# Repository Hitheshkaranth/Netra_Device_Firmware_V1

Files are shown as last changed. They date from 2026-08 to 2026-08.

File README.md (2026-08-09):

<p align="center">
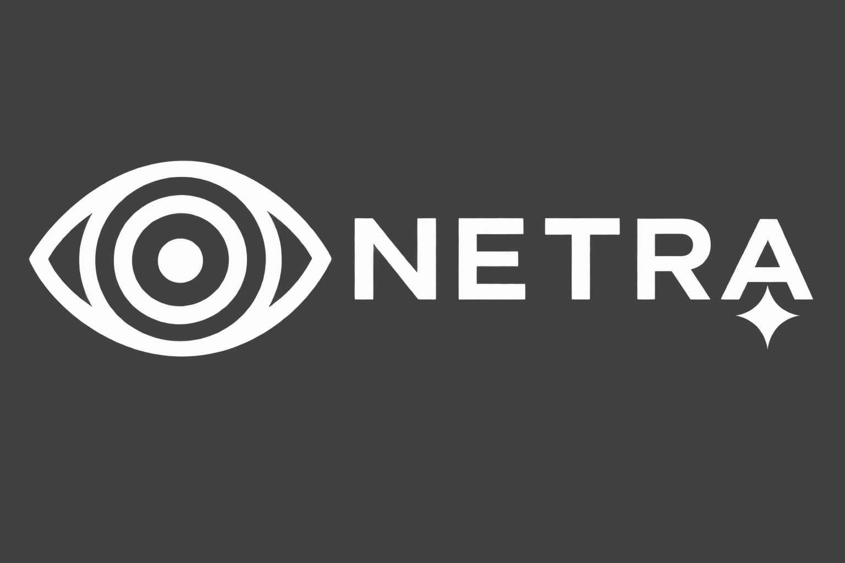
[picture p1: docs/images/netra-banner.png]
NETRA
  
</p>

<div align="center">

# NETRA Device Firmware V1

### ESP32-C6 spatial-sensing firmware for the NETRA wearable safety system








Ultrasonic ranging and six-axis motion telemetry, streamed as clean CSV over USB serial.

**Built for Claude Community Events @ Impact Lab.**

</div>

## Hardware

<p align="center">
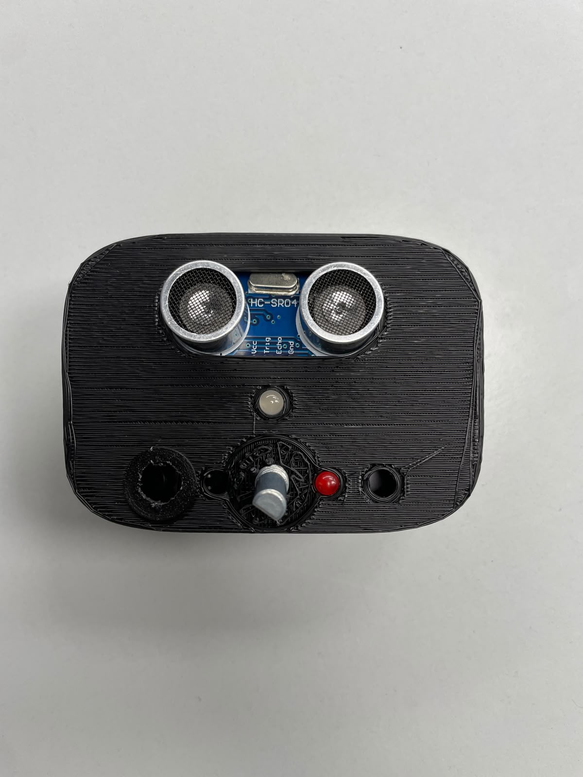
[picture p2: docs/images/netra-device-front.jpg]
NETRA device front view
  
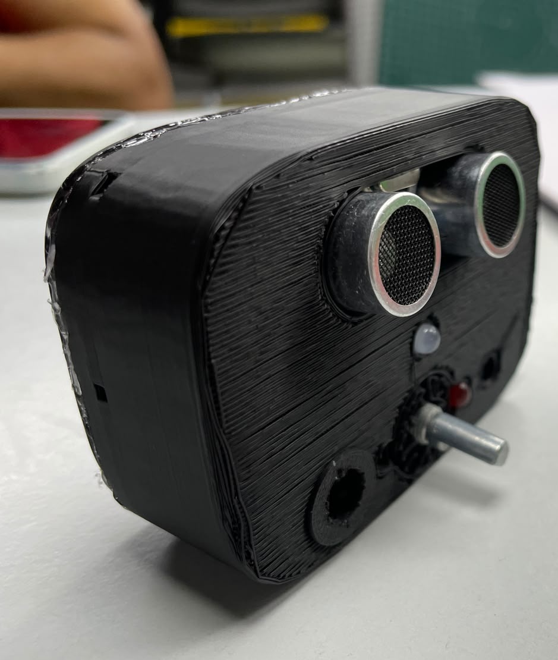
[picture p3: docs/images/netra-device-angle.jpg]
NETRA device angled view
  
</p>

The V1 sensor node combines:

| Component | Purpose | Interface |
|---|---|---|
| PCBCupid Glyph C6 / ESP32-C6 | Main controller and USB serial link | USB CDC |
| HC-SR04 | Obstacle distance measurement, nominally 2–400 cm | Trigger/echo pulse |
| MPU6050 | 3-axis acceleration, 3-axis angular velocity, temperature | I²C at `0x68` or `0x69` |

The MPU6050 is read directly through `Wire`; no third-party sensor library is required.

## Wearer movement tracking

NETRA does more than measure nearby obstacles. The device is worn by the user, so its MPU6050 continuously captures the wearer's three-axis acceleration and three-axis rotation. The firmware streams this motion telemetry to the companion debugger, where it can be used to detect movement, estimate gait intensity, follow orientation changes, and animate the user's motion inside a closed or indoor tracking environment.

This is relative inertial movement tracking rather than GPS-style absolute positioning. Long-term position estimation from an IMU alone will accumulate drift; the current system is designed for live movement state, posture/orientation response, and closed-environment visualization.

## Pin map

| Sensor pin | Board pin | GPIO | Direction | Notes |
|---|---|---:|---|---|
| HC-SR04 `VCC` | `5V` | — | Power | Use the board's 5 V rail |
| HC-SR04 `GND` | `GND` | — | Power | All grounds must be common |
| HC-SR04 `TRIG` | `D20` | 20 | Output | 10 µs trigger pulse |
| HC-SR04 `ECHO` | `D15` | 15 | Input | **Must pass through a voltage divider** |
| MPU6050 `VCC` | `3V3` | — | Power | Safe default for common breakout boards |
| MPU6050 `GND` | `GND` | — | Power | Common ground |
| MPU6050 `SDA` | `SDA` | 4 | I²C data | Internal address auto-detected |
| MPU6050 `SCL` | `SCL` | 5 | I²C clock | Bus runs at 100 kHz |

### Prototype connection

The breadboard prototype below shows the Glyph controller connected to the HC-SR04 ultrasonic sensor and MPU6050 IMU. Use the pin table above as the source of truth; jumper-wire colors may differ between builds.

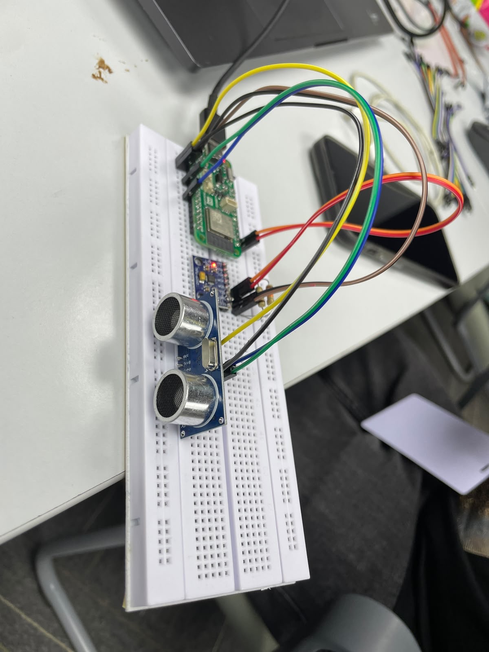
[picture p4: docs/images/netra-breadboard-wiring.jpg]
NETRA Glyph, HC-SR04, and MPU6050 breadboard connection


> [!CAUTION]
> The HC-SR04 echo output is approximately 5 V. Never connect it directly to an ESP32-C6 input. Use, for example, 1 kΩ from `ECHO` to GPIO 15 and 2 kΩ from GPIO 15 to GND to reduce the signal to approximately 3.3 V.

```text
HC-SR04 ECHO ── 1 kΩ ──┬── GPIO 15
                       │
                      2 kΩ
                       │
                      GND
```

## Build and upload

### Arduino IDE

Follow the official **[PCBCupid Arduino IDE setup guide](https://learn.pcbcupid.com/documentation/welcome/prerequisites/arduino-ide-setup)** when preparing a Glyph board. The required setup is summarized here:

1. Install the latest [Arduino IDE](https://www.arduino.cc/en/software), preferably version **2.3 or newer**.
2. Open **File → Preferences** and add this URL under **Additional Boards Manager URLs**:

   ```text
   https://raw.githubusercontent.com/espressif/arduino-esp32/gh-pages/package_esp32_index.json
   ```

3. Open **Boards Manager**, search for `ESP32`, and install **esp32 by Espressif Systems**. Use the newest available release or at least version **3.1.0**.
4. Connect the Glyph C6 with a data/sync-capable USB cable.
5. Select **Tools → Board → ESP32 Arduino → GLYPHC6**. If that entry is unavailable, select **ESP32C6 Dev Module**.
6. Open `Netra_Device_Firmware_V1.ino`, enable **Tools → USB CDC On Boot**, and select the board's COM port under **Tools → Port**.
7. Click **Verify** and confirm compilation finishes successfully, then click **Upload**.
8. After upload, open Serial Monitor at **115200 baud**.

If the COM port is missing, hold **BOOT**, press and release **RESET** while continuing to hold BOOT, then release BOOT after the board enters bootloader mode. Re-select the COM port and upload again.

### Arduino CLI

Replace `COM6` and the FQBN when using another board definition:

```powershell
arduino-cli core update-index
arduino-cli core install esp32:esp32
arduino-cli compile --fqbn esp32:esp32:esp32c6 .
arduino-cli upload -p COM6 --fqbn esp32:esp32:esp32c6 .
```

## Mechanical enclosure and 3D printing

Printable NETRA V1 enclosure and wearable-pod models are maintained separately from the firmware source under [`mechanical/`](mechanical/). The directory contains six STL parts plus slicing, printing, dry-fit, and assembly instructions.

The [interactive assembled-system viewer](mechanical/belt_system_viewer.html) renders the printable enclosure together with the belt, controller, sensors, controls, battery, and pod components. It includes ghost-shell, part-visibility, rotate, fit, and exploded-view controls.

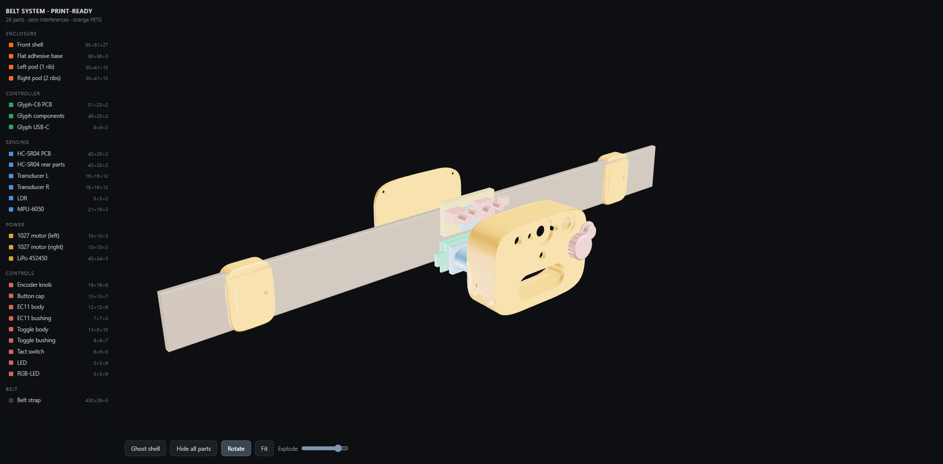
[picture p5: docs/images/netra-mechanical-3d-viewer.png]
NETRA belt system and 3D-printing assembly viewer


```text
mechanical/stl/
├── pod_1027_left.stl
├── pod_1027_right.stl
├── v2_button_cap.stl
├── v3_knob.stl
├── v7_base.stl
└── v7_shell.stl
```

See the [mechanical and 3D-printing guide](mechanical/README.md) before printing or installing electronics.

## Serial protocol

The device publishes one row every 250 ms:

```text
distance_cm,echo_us,ax_g,ay_g,az_g,gx_dps,gy_dps,gz_dps,temp_c,status
24.63,1436,0.012,-0.021,0.998,0.31,-0.18,0.07,28.41,RANGE_OK|IMU_OK
```

| Field | Unit | Meaning |
|---|---|---|
| `distance_cm` | cm | Distance calculated from the HC-SR04 echo pulse |
| `echo_us` | µs | Raw ultrasonic round-trip pulse width |
| `ax_g`…`az_g` | g | Accelerometer axes |
| `gx_dps`…`gz_dps` | °/s | Gyroscope axes |
| `temp_c` | °C | IMU die temperature |
| `status` | — | Combined range and IMU health flags |

`RANGE_TIMEOUT` indicates that no echo arrived within 30 ms. `IMU_ERROR` usually points to I²C wiring, power, or address trouble.

## Use with the NETRA debugger

Install and run the companion [Netra System Debugger V1](../Netra_System_Debugger_V1) to visualize motion, sensor health, proximity, and the live 3D digital twin.

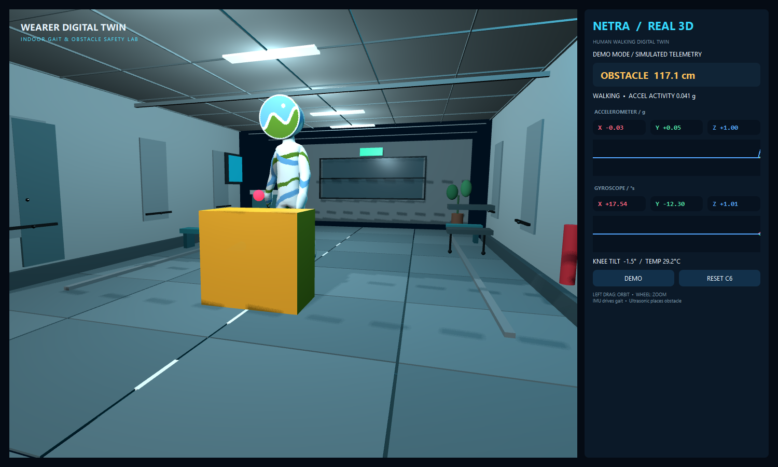
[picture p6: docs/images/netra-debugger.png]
NETRA PySide6 3D debugger


Only one application can own the serial port at a time. Close Arduino Serial Monitor before starting the debugger.

## Quick checks

- At rest, the magnitude of `(ax, ay, az)` should be close to `1 g`.
- Rotating the enclosure should change the gyroscope values.
- A flat target between 10 and 100 cm should produce a stable distance.
- If the board prints ROM download messages, tap reset and confirm **USB CDC On Boot** is enabled.

## Repository layout

```text
Netra_Device_Firmware_V1/
├── Netra_Device_Firmware_V1.ino
├── docs/images/
├── mechanical/
│   ├── README.md
│   ├── belt_system_viewer.html
│   └── stl/*.stl
├── .gitignore
└── README.md
```

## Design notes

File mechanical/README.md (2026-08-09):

# NETRA mechanical and 3D-printing files

This directory contains the printable enclosure parts for the NETRA V1 wearable sensor device. The source STL filenames are preserved so they can be traced back to the original mechanical export.

## Interactive assembled-system viewer

Open [`belt_system_viewer.html`](belt_system_viewer.html) in a modern browser to inspect the complete belt system, enclosure, controller, sensors, controls, power components, and wearable pods in an interactive 3D scene.

The viewer provides:

- orbit, pan, zoom, automatic rotation, and fit-to-view controls;
- a ghosted enclosure mode for inspecting internal placement;
- per-part visibility controls and component dimensions;
- an explode slider for separating the assembly;
- embedded model geometry, with only the Three.js runtime loaded externally.

An internet connection is required when opening the viewer because it loads Three.js from cdnjs.

NETRA belt system and printable enclosure assembly

## Printer and slicer used

The photographed NETRA enclosure print job was prepared in **Bambu Studio** for a **Bambu Lab P2S 3D printer**. The slicer preview used a 0.20 mm layer profile with automatic tree supports; the pictured plate estimated approximately 55.7 g of filament and 2 hours 10 minutes total print time. Treat these values as a record of this prototype build—re-slice the STL files for your own printer, nozzle, filament, and calibration.

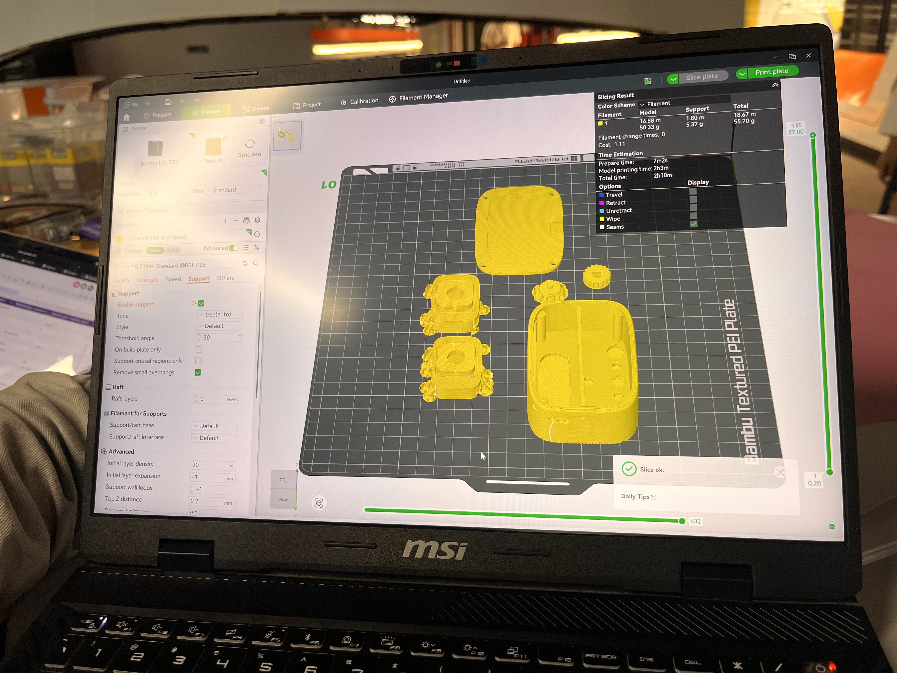
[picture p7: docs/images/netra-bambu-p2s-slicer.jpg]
NETRA enclosure parts sliced for the Bambu Lab P2S


## Included parts

| File | Intended part |
|---|---|
| [`pod_1027_left.stl`](stl/pod_1027_left.stl) | Left wearable pod component |
| [`pod_1027_right.stl`](stl/pod_1027_right.stl) | Right wearable pod component |
| [`v2_button_cap.stl`](stl/v2_button_cap.stl) | External button cap |
| [`v3_knob.stl`](stl/v3_knob.stl) | User-control knob |
| [`v7_base.stl`](stl/v7_base.stl) | Main enclosure base |
| [`v7_shell.stl`](stl/v7_shell.stl) | Main enclosure shell/top cover |

## Prepare the files

1. Download this repository or the individual STL files.
2. Import the required models from `mechanical/stl/` into Cura, PrusaSlicer, OrcaSlicer, Bambu Studio, or another STL-compatible slicer.
3. Treat the models as millimetres. Confirm the displayed dimensions before slicing; do not rescale unless your slicer imported them in another unit.
4. Place the largest flat surface on the build plate where practical.
5. Inspect the HC-SR04 openings, button/knob features, overhangs, and internal mounting points in the layer preview. Enable supports only where the selected orientation needs them.

## Suggested starting profile

These values are a safe prototype starting point, not a substitute for tuning your printer and material:

| Setting | Starting value |
|---|---|
| Material | PLA for prototypes; PETG for improved impact/heat resistance |
| Layer height | 0.20 mm |
| Walls/perimeters | 3 |
| Top and bottom layers | 4–5 |
| Infill | 20–30% |
| Supports | Build plate only, where required by preview |
| Brim | Optional for pod parts or a small bed-contact area |

## Assembly workflow

1. Print one `v7_base`, one `v7_shell`, the button cap, the knob, and the pod parts needed by your wearable configuration.
2. Remove supports and carefully deburr sensor, control, cable, and fastener openings.
3. Dry-fit the HC-SR04, controller, controls, and enclosure halves before installing fasteners or adhesive.
4. Check that the button cap and knob move freely without holding the internal switches permanently active.
5. Route wiring away from enclosure edges and moving controls. Keep the HC-SR04 transducers unobstructed.
6. Confirm the HC-SR04 echo voltage divider and common grounds before powering the assembled device.

> [!CAUTION]
> Printer tolerances and component dimensions vary. Do not force electronics into a tight print. Adjust slicer compensation or lightly finish the relevant opening, then dry-fit again.

## Directory layout

```text
mechanical/
├── README.md
├── belt_system_viewer.html
└── stl/
    ├── pod_1027_left.stl
    ├── pod_1027_right.stl
    ├── v2_button_cap.stl
    ├── v3_knob.stl
    ├── v7_base.stl
    └── v7_shell.stl
```

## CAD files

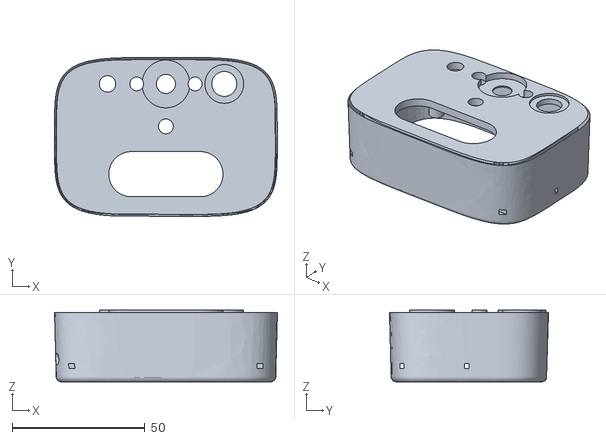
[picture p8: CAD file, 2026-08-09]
mechanical/stl/v7_shell.stl
84.0 x 59.9 x 27.0

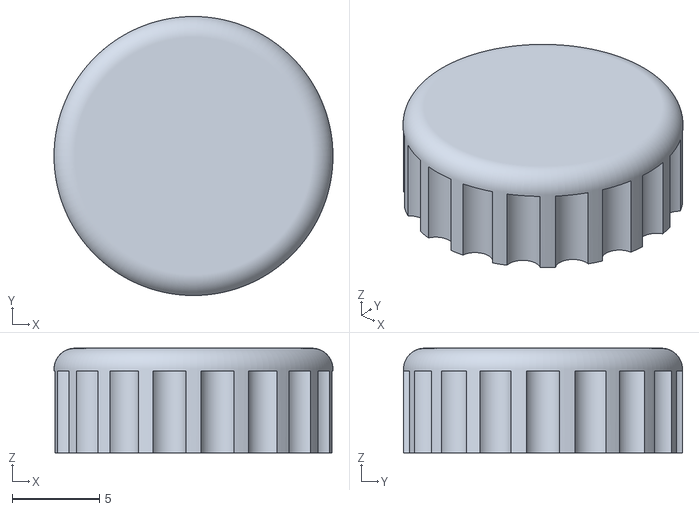
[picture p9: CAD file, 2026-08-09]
mechanical/stl/v3_knob.stl
16.0 x 16.0 x 6.00

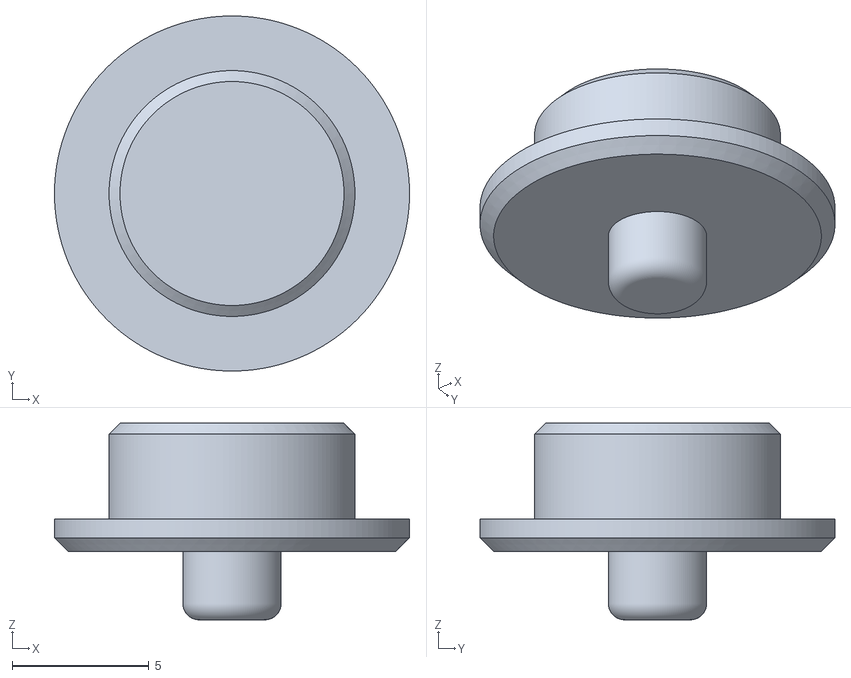
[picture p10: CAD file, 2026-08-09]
mechanical/stl/v2_button_cap.stl
13.0 x 13.0 x 7.20

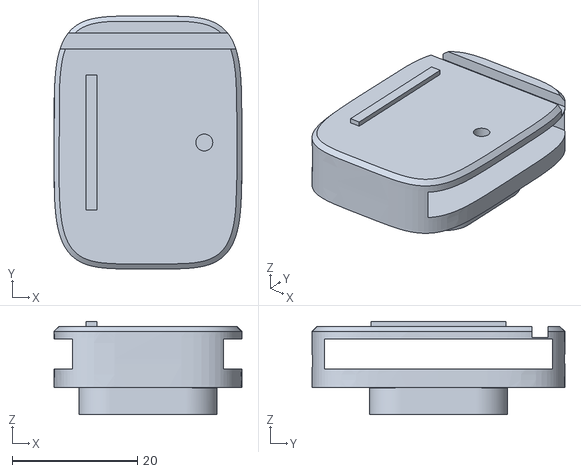
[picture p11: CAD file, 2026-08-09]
mechanical/stl/pod_1027_right.stl
30.0 x 40.4 x 14.9

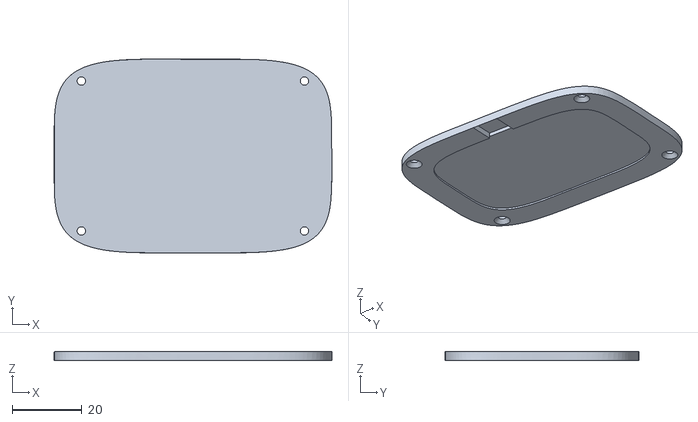
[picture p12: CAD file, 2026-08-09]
mechanical/stl/v7_base.stl
79.7 x 55.7 x 2.50

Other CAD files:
mechanical/stl/pod_1027_left.stl

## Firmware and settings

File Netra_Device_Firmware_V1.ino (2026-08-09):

#include <Arduino.h>
#include <Wire.h>

// PCBCupid Glyph C6 wiring.
constexpr uint8_t ECHO_PIN = 15;  // Board pin D15, through divider.
constexpr uint8_t TRIG_PIN = 20;  // Board pin D20.
constexpr uint8_t SDA_PIN = 4;    // Board pin SDA.
constexpr uint8_t SCL_PIN = 5;    // Board pin SCL.

constexpr uint32_t SERIAL_BAUD = 115200;
constexpr uint32_t ECHO_TIMEOUT_US = 30000;  // About 5 m maximum round trip.
constexpr uint32_t SAMPLE_PERIOD_MS = 250;

// The HC-SR04 is only specified from 2 cm to 400 cm. The echo timeout allows
// more than that, so readings beyond these bounds are reported as out of spec
// rather than passed off as measurements.
constexpr float RANGE_MIN_CM = 2.0f;
constexpr float RANGE_MAX_CM = 400.0f;

// Approximated range: the median of the last few valid readings. A median
// rejects the isolated wild values this sensor produces on a glancing or soft
// target, which a mean would instead smear across several samples.
constexpr uint8_t RANGE_WINDOW = 5;

// Proximity bands for the approximated range, nearest first.
constexpr float ZONE_IMMEDIATE_CM = 25.0f;
constexpr float ZONE_NEAR_CM = 60.0f;
constexpr float ZONE_MID_CM = 120.0f;
constexpr float ZONE_FAR_CM = 250.0f;

enum RangeStatus : uint8_t {
  RANGE_STATUS_OK,
  RANGE_STATUS_TIMEOUT,
  RANGE_STATUS_OUT_OF_SPEC,
};

uint8_t mpuAddress = 0;
uint8_t mpuWhoAmI = 0;

float rangeWindow[RANGE_WINDOW];
uint8_t rangeWriteIndex = 0;
uint8_t rangeFilled = 0;

bool writeMpuRegister(uint8_t reg, uint8_t value) {
  Wire.beginTransmission(mpuAddress);
  Wire.write(reg);
  Wire.write(value);
  return Wire.endTransmission() == 0;
}

bool readMpuRegisters(uint8_t firstRegister, uint8_t *data, size_t length) {
  Wire.beginTransmission(mpuAddress);
  Wire.write(firstRegister);
  if (Wire.endTransmission(false) != 0) {
    return false;
  }

  const size_t received = Wire.requestFrom(mpuAddress, static_cast<uint8_t>(length),
                                           static_cast<uint8_t>(true));
  if (received != length) {
    return false;
  }

  for (size_t i = 0; i < length; ++i) {
    data[i] = Wire.read();
  }
  return true;
}

// A genuine MPU6050 reports WHO_AM_I 0x68, but boards sold as one are often
// MPU6500/MPU9250 parts or clones reporting something else entirely. Their
// accelerometer, gyroscope and configuration registers are compatible, so an
// unexpected value is reported and accepted rather than failing the probe.
uint8_t findMpu6050(bool verbose = false) {
  const uint8_t candidates[] = {0x68, 0x69};
  for (uint8_t address : candidates) {
    Wire.beginTransmission(address);
    if (Wire.endTransmission() != 0) {
      continue;
    }

    mpuAddress = address;
    uint8_t whoAmI = 0;
    if (!readMpuRegisters(0x75, &whoAmI, 1)) {
      if (verbose) {
        Serial.printf("0x%02X acknowledged its address but WHO_AM_I would not read\n",
                      address);
      }
      mpuAddress = 0;
      continue;
    }

    if (verbose && whoAmI != 0x68 && whoAmI != 0x69) {
      Serial.printf("0x%02X reports WHO_AM_I 0x%02X, not a genuine MPU6050; using it anyway\n",
                    address, whoAmI);
    }
    mpuWhoAmI = whoAmI;
    return address;
  }
  mpuAddress = 0;
  return 0;
}

bool initialiseMpu6050(bool verbose = false) {
  if (findMpu6050(verbose) == 0) {
    return false;
  }

  // Wake up, use the X gyroscope PLL, select +/-2 g and +/-250 deg/s.
  return writeMpuRegister(0x6B, 0x01) &&
         writeMpuRegister(0x1C, 0x00) &&
         writeMpuRegister(0x1B, 0x00) &&
         writeMpuRegister(0x1A, 0x03);
}

bool readMpu6050(float &ax, float &ay, float &az,
                 float &temperatureC, float &gx, float &gy, float &gz) {
  uint8_t raw[14];
  if (!readMpuRegisters(0x3B, raw, sizeof(raw))) {
    return false;
  }

  const int16_t rawAx = static_cast<int16_t>((raw[0] << 8) | raw[1]);
  const int16_t rawAy = static_cast<int16_t>((raw[2] << 8) | raw[3]);
  const int16_t rawAz = static_cast<int16_t>((raw[4] << 8) | raw[5]);
  const int16_t rawTemp = static_cast<int16_t>((raw[6] << 8) | raw[7]);
  const int16_t rawGx = static_cast<int16_t>((raw[8] << 8) | raw[9]);
  const int16_t rawGy = static_cast<int16_t>((raw[10] << 8) | raw[11]);
  const int16_t rawGz = static_cast<int16_t>((raw[12] << 8) | raw[13]);

  ax = rawAx / 16384.0f;
  ay = rawAy / 16384.0f;
  az = rawAz / 16384.0f;
  // The MPU6050 and the MPU6500/MPU9250 parts sold under its name scale
  // temperature differently. Accelerometer and gyroscope sensitivities match,
  // so only this conversion has to branch.
  if (mpuWhoAmI == 0x68 || mpuWhoAmI == 0x69) {
    temperatureC = rawTemp / 340.0f + 36.53f;
  } else {
    temperatureC = rawTemp / 333.87f + 21.0f;
  }
  gx = rawGx / 131.0f;
  gy = rawGy / 131.0f;
  gz = rawGz / 131.0f;
  return true;
}

// Report every I2C address that answers, so a missing MPU6050 can be told
// apart from one strapped to an unexpected address or a dead bus.
void scanI2cBus() {
  uint8_t found = 0;
  Serial.print("I2C scan:");
  for (uint8_t address = 0x08; address < 0x78; ++address) {
    Wire.beginTransmission(address);
    if (Wire.endTransmission() == 0) {
      Serial.printf(" 0x%02X", address);
      ++found;
    }
  }
  if (found == 0) {
    Serial.print(" no devices responded");
  }
  Serial.println();
}

bool readDistanceCm(float &distanceCm, uint32_t &echoUs) {
  // A burst still echoing from the previous cycle would make pulseIn measure
  // the tail of that one instead of ours.
  const uint32_t idleStart = micros();
  while (digitalRead(ECHO_PIN) == HIGH) {
    if (micros() - idleStart > ECHO_TIMEOUT_US) {
      echoUs = 0;
      return false;
    }
  }

  digitalWrite(TRIG_PIN, LOW);
  delayMicroseconds(2);
  digitalWrite(TRIG_PIN, HIGH);
  delayMicroseconds(10);
  digitalWrite(TRIG_PIN, LOW);

  echoUs = pulseIn(ECHO_PIN, HIGH, ECHO_TIMEOUT_US);
  if (echoUs == 0) {
    return false;
  }

  // At approximately 20 C, sound travels 0.0343 cm/us. Divide by two
  // because the measured time includes the trip to the target and back.
  distanceCm = echoUs * 0.0343f / 2.0f;
  return true;
}

void setup() {
  Serial.begin(SERIAL_BAUD);
  delay(1000);

  pinMode(TRIG_PIN, OUTPUT);
  pinMode(ECHO_PIN, INPUT);
  digitalWrite(TRIG_PIN, LOW);

  Wire.begin(SDA_PIN, SCL_PIN);
  // 100 kHz. Clone breakout boards on jumper wires often ACK an address at
  // 400 kHz but fail longer register reads.
  Wire.setClock(100000);

  Serial.println();
  Serial.println("========================================");
  Serial.println("  Project NETRA");
  Serial.println("  ESP32-C6 sensor node");
  Serial.println("  HC-SR04 ultrasonic + MPU6050 IMU");
  Serial.println("========================================");
  if (initialiseMpu6050(true)) {
    Serial.printf("MPU6050 found at I2C address 0x%02X\n", mpuAddress);
  } else {
    Serial.println("ERROR: MPU6050 not found at 0x68 or 0x69");
    scanI2cBus();
  }
  Serial.println("distance_cm,echo_us,ax_g,ay_g,az_g,gx_dps,gy_dps,gz_dps,temp_c,status");
}

void loop() {
  float distanceCm = NAN;
  uint32_t echoUs = 0;
  float ax = NAN, ay = NAN, az = NAN;
  float gx = NAN, gy = NAN, gz = NAN, temperatureC = NAN;

  const bool rangeOk = readDistanceCm(distanceCm, echoUs);
  bool imuOk = false;
  if (mpuAddress != 0) {
    imuOk = readMpu6050(ax, ay, az, temperatureC, gx, gy, gz);
  } else {
    initialiseMpu6050();  // Allow a sensor connected after boot to recover.
  }

  // One buffered write per sample. The USB CDC endpoint drops whole writes
  // when its FIFO is full, which shredded fields when this was 22 separate
  // print calls. Unset values are already NAN and format as "nan".
  char line[192];
  snprintf(line, sizeof(line),
           "%.2f,%lu,%.3f,%.3f,%.3f,%.2f,%.2f,%.2f,%.2f,%s|%s\r\n",
           distanceCm, static_cast<unsigned long>(echoUs), ax, ay, az,
           gx, gy, gz, temperatureC,
           rangeOk ? "RANGE_OK" : "RANGE_TIMEOUT",
           imuOk ? "IMU_OK" : "IMU_ERROR");
  Serial.print(line);

  delay(SAMPLE_PERIOD_MS);
}

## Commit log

2026-08-09 Initial NETRA device firmware release
2026-08-09 Add mechanical 3D printing files
    [pod_1027_left.stl, pod_1027_right.stl, v2_button_cap.stl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]
2026-08-09 Document firmware setup and prototype build
